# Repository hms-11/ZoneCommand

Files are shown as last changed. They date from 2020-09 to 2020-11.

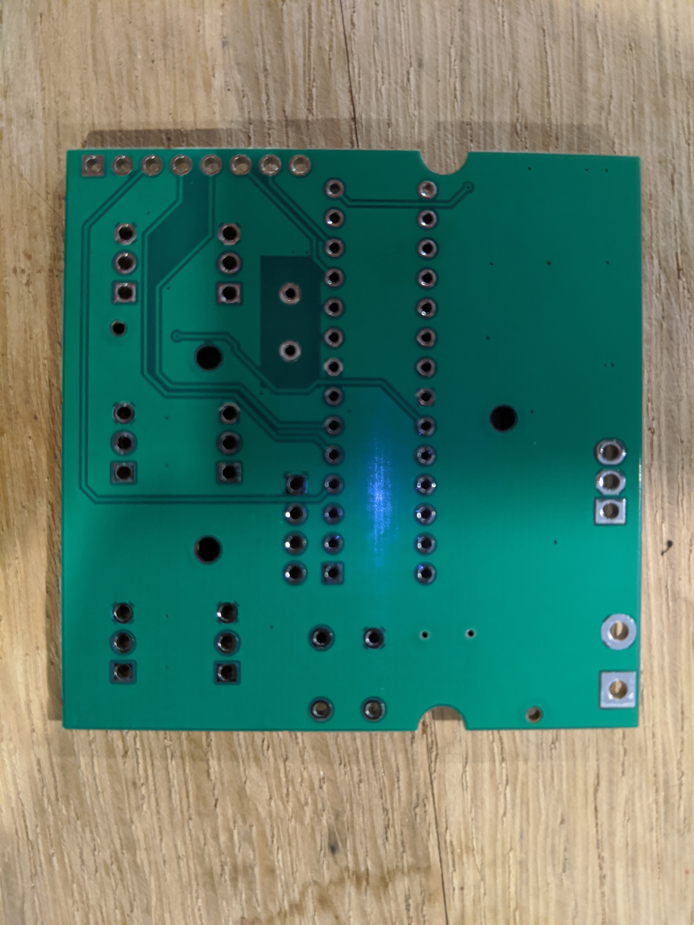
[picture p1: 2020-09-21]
IMG_20200921_071650.jpg

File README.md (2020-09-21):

# ZoneCommand
6 - Zone Control Board based on ATMEGA328P IC
Open Source 6 Zone Control Board designed to be easily configurable for a wide range of applications. 
This designed to be powered off of any 12V supply with its own on board voltage regulator (7805 footprint) to supply 5V to the board.
All inputs have an ADC as well as on-board RC filters for noise mitigation. 
Each zone has a corresponding indicator LED to let you know if the zone is active.
Outputs can be easily configured between active HIGH (5V) and active LOW (0V) in code.
Output had dedicated 5V and GND pins for outputs requiring power. 
Programming through TXD/RXD pins using a USB/Serial adapter.
All settings aim to be easily settable by the non-familiar with coding. All configuration settings aim to be well labled in the code.

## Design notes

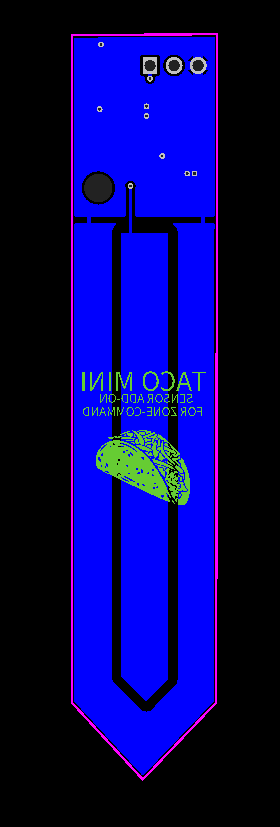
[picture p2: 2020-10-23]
PCB_PCB_2020-09-21_15-45-36_2020-10-23_11-47-11.png

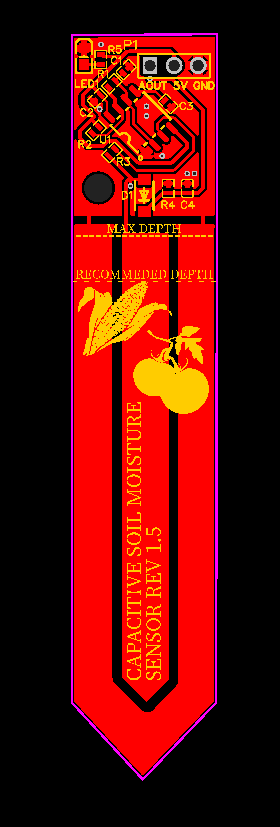
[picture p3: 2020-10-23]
PCB_PCB_2020-09-21_15-45-36_2020-10-23_11-46-59.png

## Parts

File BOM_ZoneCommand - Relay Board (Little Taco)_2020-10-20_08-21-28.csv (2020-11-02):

ID | Name | Designator | Footprint | Quantity | Manufacturer Part | Manufacturer | Supplier | Supplier Part | LCSC Assembly
1 | MMBT5551_C2145 | Q1,Q2,Q3,Q4,Q5,Q6 | SOT-23-3_L2.9-W1.3-P1.90-LS2.4-BR | 6 | MMBT5551 | CJ | LCSC | C2145 | Yes
2 | 10uF | C1 | C0805 | 1 | CL21A106KAYNNNE | SAMSUNG | LCSC | C15850 | Yes
3 | FC-2012HRK-620D | LED1,LED2,LED3,LED4,LED5,LED6 | LED0805-RD | 6 | FC-2012HRK-620D | NATIONSTAR | LCSC | C84256 | Yes
4 | 330 | R1,R2,R3,R4,R5,R6 | R0805 | 6 | 0805W8F3300T5E | UniOhm | LCSC | C17630 | Yes
5 | JQ1P-5V-F | K1,K2,K3,K4,K5,K6 | RELAY-TH_JQ1P-5V-F | 6 | JQ1P-5V-F | PANASONIC | LCSC | C58271
6 | 08JQ-BT | CN7 | CONN-TH_8P-P2.50_08JQ-BT | 1 | 08JQ-BT | JST Sales America | LCSC | C163025
7 | XY2500R-A-5.00-3P | CN1,CN2,CN3,CN4,CN5,CN6 | CONN-TH_XY2500R-A-5.00-3P | 6 | XY2500R-A-5.00-3P | -- | LCSC | C505798
8 | 510 | R7,R8,R9,R10,R11,R12 | R0805 | 6 | 0805W8F5100T5E | UniOhm | LCSC | C17734 | Yes
9 | 10K | R13,R14,R15,R16,R17,R18 | R0805 | 6 | 0805W8F1002T5E | UniOhm | LCSC | C17414 | Yes
10 | SM4007PL | D1,D2,D3,D4,D5,D6 | SOD-123F_L2.8-W1.8-LS3.7-RD | 6 | SM4007PL | MDD | LCSC | C64898 | Yes

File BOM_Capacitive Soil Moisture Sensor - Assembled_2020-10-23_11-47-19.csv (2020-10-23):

ID | Name | Designator | Footprint | Quantity | Manufacturer Part | Manufacturer | Supplier | Supplier Part | LCSC Assembly
1 | 470pF | C1 | C0402 | 1 | 0402B471K500NT | FH | LCSC | C1537 | Yes
2 | 10nF | C3 | C0402 | 1 | CL05B103KB5NNNC | SAMSUNG | LCSC | C15195 | Yes
3 | 10K | R3 | R0402 | 1 | 0402WGF1002TCE | UniOhm | LCSC | C25744 | Yes
4 | 330 | R2 | R0402 | 1 | 0402WGF3300TCE | UniOhm | LCSC | C25104 | Yes
5 | 1.6K | R1 | R0402 | 1 | 0402WGF1601TCE | UniOhm | LCSC | C4908 | Yes
6 | 1K | R5 | R0402 | 1 | 0402WGF1001TCE | UniOhm | LCSC | C11702 | Yes
7 | 1M | R4 | R0402 | 1 | 0402WGF1004TCE | UniOhm | LCSC | C26083 | Yes
8 | 1nF | C4 | C0402 | 1 | 0402B102K500NT | FH | LCSC | C1523 | Yes
9 | KT-0603R | LED1 | LED0603-R-RD | 1 | KT-0603R | KENTO | LCSC | C2286 | Yes
10 | NE555DR | U1 | SOIC-8_L4.9-W3.9-P1.27-LS6.0-BL | 1 | NE555DR | TI | LCSC | C7593 | Yes
11 | Header-Female-2.54_1x3 | P1 | HDR-TH_3P-P2.54-V | 1 | Header-Female-2.54_1x3 | Boom Precision Elec | LCSC | C146243
12 | 100nF | C2 | C0402 | 1 | CL05B104KO5NNNC | SAMSUNG | LCSC | C1525 | Yes
13 | SM4007PL | D1 | SOD-123F_L2.8-W1.8-LS3.7-RD | 1 | SM4007PL | MDD | LCSC | C64898 | Yes

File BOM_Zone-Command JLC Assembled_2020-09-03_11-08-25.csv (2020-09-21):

ID | Name | Designator | Footprint | Quantity | Manufacturer Part | Manufacturer | Supplier | Supplier Part | LCSC Assembly
1 | 22pF | C17,C9 | C0805 | 2 | CL21C220JBANNNC | SAMSUNG | LCSC | C1804 | Yes
2 | 100nF | C5,C19,C20,C21,C22,C23,C24,C11,C12,C13,C15,C16,C4,C6,C7,C3,C2,C8,C10 | C0805 | 19 | CC0805KRX7R9BB104 | YAGEO | LCSC | C49678 | Yes
3 | 10uF | C18 | C0805 | 1 | CL21A106KAYNNNE | SAMSUNG | LCSC | C15850 | Yes
4 | 1K | R4,R1,R10,R11,R12,R13,R14 | R0805 | 7 | 0805W8F1001T5E | UniOhm | LCSC | C17513 | Yes
5 | Sens6 | H7 | HDR-TH_3P-P2.54-V | 1 | Header2.54mm 1*3P | BOOMELE | LCSC | C49257
6 | Sens4 | H5 | HDR-TH_3P-P2.54-V | 1 | Header2.54mm 1*3P | BOOMELE | LCSC | C49257
7 | Sens5 | H4 | HDR-TH_3P-P2.54-V | 1 | Header2.54mm 1*3P | BOOMELE | LCSC | C49257
8 | Sens2 | H3 | HDR-TH_3P-P2.54-V | 1 | Header2.54mm 1*3P | BOOMELE | LCSC | C49257
9 | Sens1 | H2 | HDR-TH_3P-P2.54-V | 1 | Header2.54mm 1*3P | BOOMELE | LCSC | C49257
10 | Sens3 | H6 | HDR-TH_3P-P2.54-V | 1 | Header2.54mm 1*3P | BOOMELE | LCSC | C49257
11 | RB050LA-30TR | D1 | SOD-128_L3.7-W2.5-LS4.7-RD | 1 | RB050LA-30TR | ROHM Semicon | LCSC | C162057 | Yes
12 | MGGB2012M181HT-LF | L2 | L0805 | 1 | MGGB2012M181HT-LF | microgate | LCSC | C486339
13 | FC-2012HRK-620D | LED8,LED7,LED6,LED5,LED2,LED1,LED4,LED3 | LED0805-RD | 8 | FC-2012HRK-620D | NATIONSTAR | LCSC | C84256 | Yes
14 | 2PIN 12V INPUT | U4 | CONN-TH_DG500-5.08-02P-14-00A(H) | 1 | DG500-5.08-02P-14-00A(H) | DEGSON | LCSC | C691859
15 | 330 | R15,R2,R3,R5,R6,R7,R8 | R0805 | 7 | 0805W8F3300T5E | UniOhm | LCSC | C17630 | Yes
16 | Button-Reset | SW1 | SW-TH_4PIN-L6.00-W6.00 | 1 | Switch,6*6*6Plastic head,260G, 0.25mm,Straight line | BBJ | LCSC | C71836
17 | ATMEGA328P-PU | U1 | DIP-28_L34.6-W7.3-P2.54-LS10.2-BL | 1 | ATMEGA328P-PU | MICROCHIP | LCSC | C33901
18 | Programming Header 1x4 | H1 | HDR-TH_4P-P2.54-V | 1 | 210S-1*4P L=11.6MMGold-plated black | Ckmtw | LCSC | C124378
19 | L7805CV | U2 | TO-220-3_L10.0-W4.5-P2.54-L | 1 | L7805CV | STMicroelectronics | LCSC | C111887
20 | 8PIN RELAY | P1 | HDR-TH_8P-P2.54-V | 1 | Female headerHDR1X8-2.54 | BOOMELE | LCSC | C27438
21 | 10K | R16 | R0805 | 1 | 0805W8F1002T5E | UniOhm | LCSC | C17414 | Yes
22 | 1uF | C25,C1 | C0805 | 2 | CL21B105KBFNNNE | SAMSUNG | LCSC | C28323 | Yes
23 | 16MHZ | X1 | HC-49S_L11.0-W4.4-P4.88 | 1 | 5S0-1600A1620-00 | XTY | LCSC | C389708

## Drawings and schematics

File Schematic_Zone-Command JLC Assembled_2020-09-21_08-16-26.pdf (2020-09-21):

## INDICATOR LEDS

## MCU SUPPORT

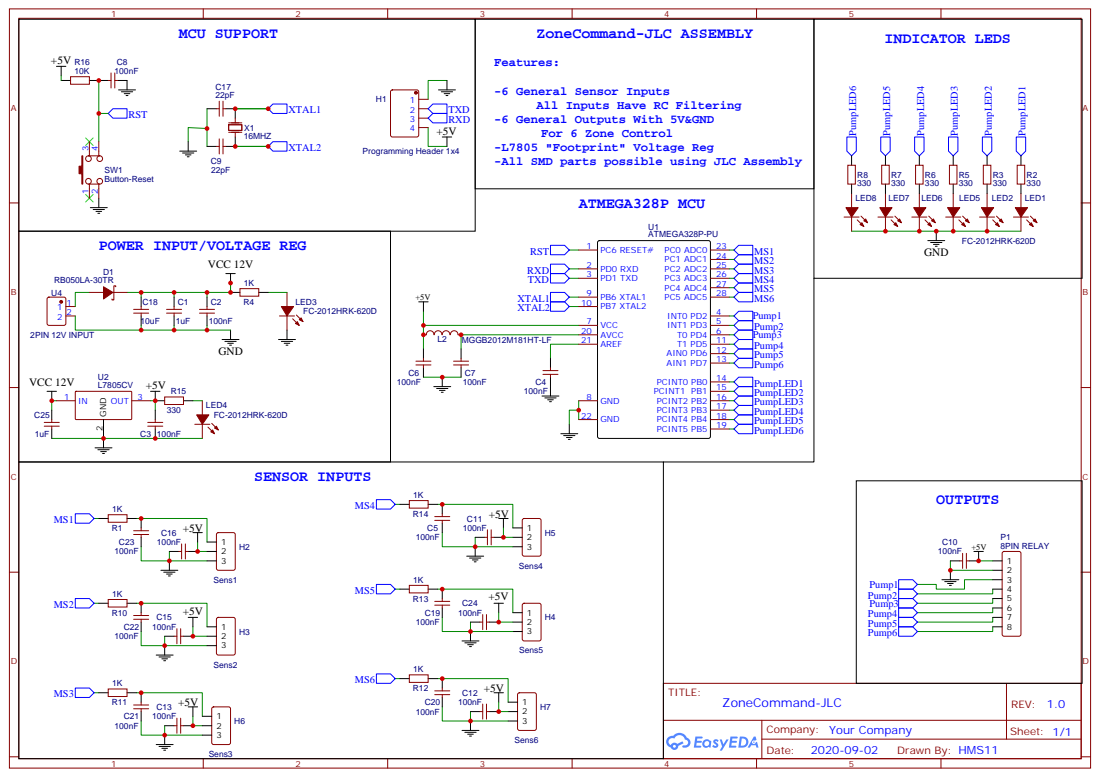
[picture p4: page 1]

All Inputs Have RC Filtering

-6 General Outputs With 5V&GND

-L7805 "Footprint" Voltage Reg
-All SMD parts possible using JLC Assembly

POWER INPUT/VOLTAGE REG

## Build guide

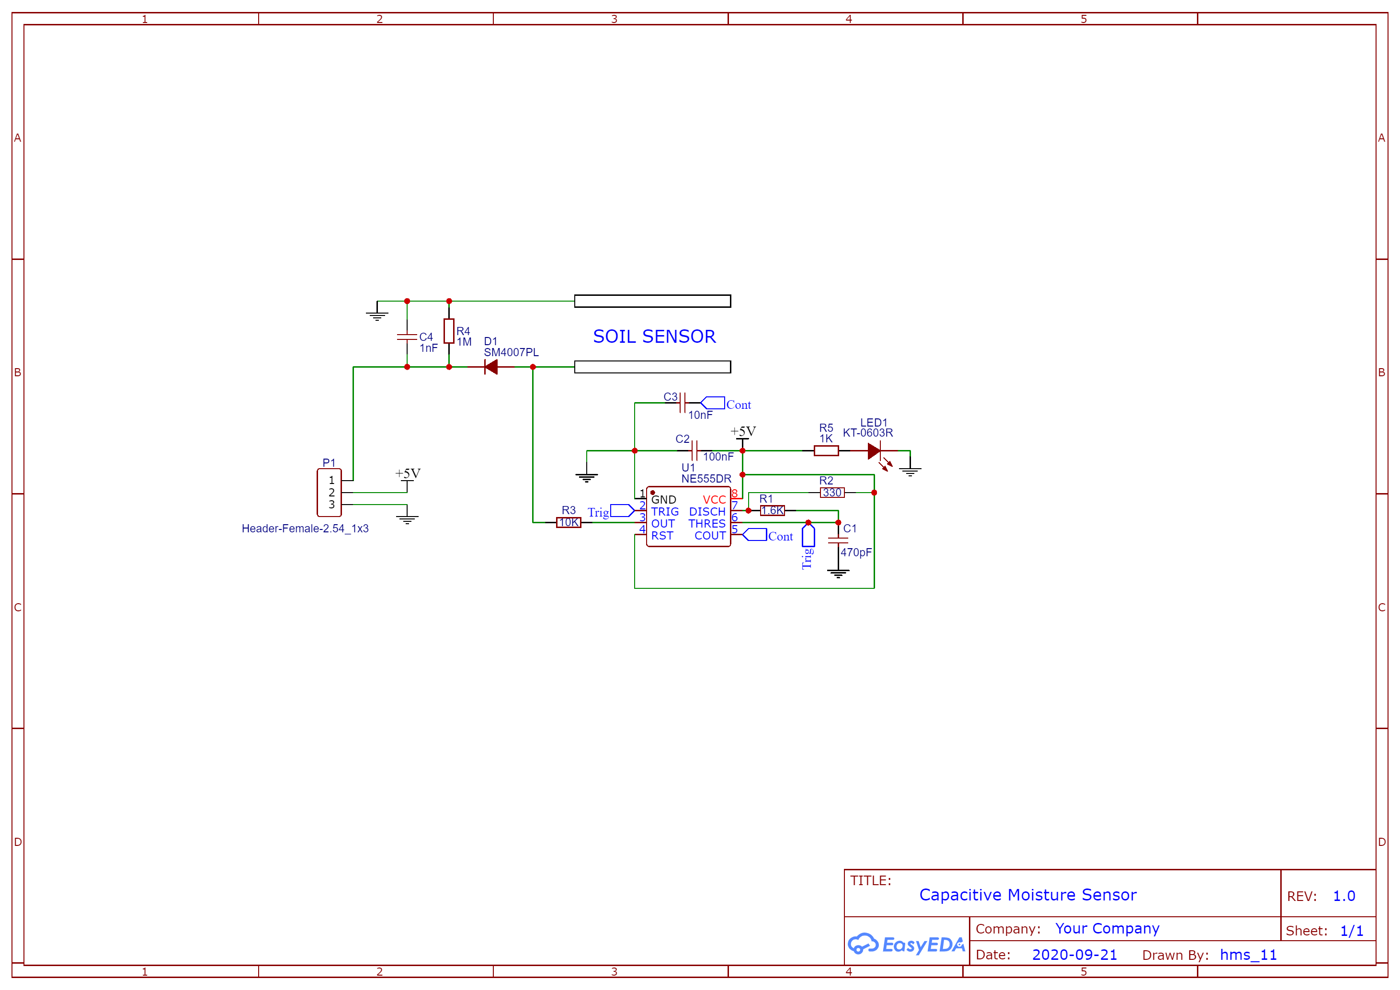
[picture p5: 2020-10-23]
Schematic_Capacitive Soil Moisture Sensor - Assembled_2020-10-23_11-46-45.png

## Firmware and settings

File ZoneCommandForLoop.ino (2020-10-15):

//  ------------------------- ZONE COMMAND ---------------------
//  ---------------------6 ZONE CONTROL BOARD-------------------

//  -------------------DESIGNED AND PROGRAMMED BY:--------------
// --------------------------COREY EARL-------------------------
// -------REVISION 3 (Simplified Code) (OCTOBER 12th, 2020)-----
// --------------All Zones Appear to Function And Debug---------
// ---------------------More Testing Needed--------------------
//----------------Ready for on-site BETA testing---------------


// print debug messages or not to serial
const bool serialDisplay = true;


///  ---------------SETTINGS-----------------

// Which zones are active. If a zone is active set as true, if a zone is deactived or not needed set to false. Zones are then placed in an array.

const bool zone1Active = true;
const bool zone2Active = true;
const bool zone3Active = true;
const bool zone4Active = true;
const bool zone5Active = true;
const bool zone6Active = true;
const bool zoneActive[6] {zone1Active, zone2Active, zone3Active, zone4Active, zone5Active, zone6Active};

// Counters for progressing through each Zone

int zoneNumber = 0; // Which zone the loop is controlling
int serialNumber = 0; // Which zone the Serial Debugger is showing

// If the relay goes active when driven low set this to true, if the relays go active when drive high set to false

const bool relayLow = true;

// If you want to trigger the outputs based on a falling value set this to true, if you want to trigger based on a raising input, set to false

const bool fallingTrigger = true;


// Sensor trigger points to trigger each zones output on. High or low "on" decided by relayLow setting

// NOTE: GIKFUN 1.2 Moisture sensors seem to range from ~340(Capacitor submerged in water) to ~670(Dry air)
//       GIKFUN 2.0 Seem to run this range (~290 wet, ~700 Dry) but responds much slower as moisture increases, responds quickly to drying).
//       These tests done with factory ~8" jumper harness. Will retest with final length harnesses and adjust



// Zone 1 setpoints
int trigger1Low = 330;
int trigger1High = 400;

// Zone 2 setpoints
int trigger2Low = 330;
int trigger2High = 400;

// Zone 3 setpoints
int trigger3Low = 330;
int trigger3High = 400;

// Zone 4 setpoints
int trigger4Low = 330;
int trigger4High = 400;

// Zone 5 setpoints
int trigger5Low = 330;
int trigger5High = 400;

// Zone 6 setpoints
int trigger6Low = 330;
int trigger6High = 400;

// Zone setpoint arrays

int triggerHigh[] {trigger1High, trigger2High, trigger3High, trigger4High, trigger5High, trigger6High}; // Puts triggerLow points in an array
int triggerLow[] {trigger1Low, trigger2Low, trigger3Low, trigger4Low, trigger5Low, trigger6Low}; // Puts triggerHigh points in an array


//// -------------------CODE----------------------

// ---Pin Assignments--

// Set Pin Assignments for Zone Status LED's

const int zone1 = 8;
const int zone2 = 9;
const int zone3 = 10;
const int zone4 = 11;
const int zone5 = 12;
const int zone6 = 13;
const int zoneLED[] {zone1, zone2, zone3, zone4, zone5, zone6}; // Puts output LEDs in an array


// Set pin assignments for OUT pins


const int out1 = 2;
const int out2 = 3;
const int out3 = 4;
const int out4 = 5;
const int out5 = 6;
const int out6 = 7;
const int output[] {out1, out2, out3, out4, out5, out6}; // Puts output pins in an array

// Set pin asignments for sensor inputs and read delays (done with millis, not delay)

const byte sens1 = A0;
const byte sens2 = A1;
const byte sens3 = A2;
const byte sens4 = A3;
const byte sens5 = A4;
const byte sens6 = A5;
const byte sens[] {sens1, sens2, sens3, sens4, sens5, sens6}; // Put analog input pins in an array

// --Variables--

// Delay Variables

const int sensorReadDelay[] {500, 500, 500, 500, 500, 500}; // delay between sensor readings in millis
unsigned long lastSensorReadTime[] {0, 0, 0, 0, 0, 0}; //the last time a sensor was read
unsigned long serialDelay = 3000; // delay between printing to serial monitor in millis
unsigned long lastSerialPrintTime = 0; // the last time the serial monitor was printed too


// Analog sensor reading values sensors 1-6
int sensor[6]; //Sensor reading values array


// Sensor pins 1-6 states ("1" = Low, "2" = Neutral, "3" = High)
int zoneState1;
int zoneState2;
int zoneState3;
int zoneState4;
int zoneState5;
int zoneState6;
int zoneState[] {zoneState1, zoneState2, zoneState3, zoneState4, zoneState5, zoneState6}; //Zone pin state array

// Output pin values outputs 1-6

int outRead1;
int outRead2;
int outRead3;
int outRead4;
int outRead5;
int outRead6;
int outRead[] {outRead1, outRead2, outRead3, outRead4, outRead5, outRead6}; // Output pin array

// Output LED pin values outputs 1-6

int outReadLED1;
int outReadLED2;
int outReadLED3;
int outReadLED4;
int outReadLED5;
int outReadLED6;
int ledState[] {outReadLED1, outReadLED2, outReadLED3, outReadLED4, outReadLED5, outReadLED6}; // Zone Active LED high/low array

// Serial States where neede
void setup() {

  // start the serial monitor and display welcome message
  Serial.begin(9600);
  delay(1000);
  Serial.println( "           Processes Started   ");
  Serial.println("           --ZONE COMMAND VERSION 1.5 (FOR LOOP CONTROL)--    ");
  Serial.println("            --6 ZONE CONTROL BOARD--     ");
  Serial.println("                       --                ");

  // set LED indicator pins to output.
  pinMode(zone1, OUTPUT);
  pinMode(zone2, OUTPUT);
  pinMode(zone3, OUTPUT);
  pinMode(zone4, OUTPUT);
  pinMode(zone5, OUTPUT);
  pinMode(zone6, OUTPUT);
  // set OUT pins to output
  pinMode(out1, OUTPUT);
  pinMode(out2, OUTPUT);
  pinMode(out3, OUTPUT);
  pinMode(out4, OUTPUT);
  pinMode(out5, OUTPUT);
  pinMode(out6, OUTPUT);
  // set sensor pins to input
  pinMode(sens1, INPUT);
  pinMode(sens2, INPUT);
  pinMode(sens3, INPUT);
  pinMode(sens4, INPUT);
  pinMode(sens5, INPUT);
  pinMode(sens6, INPUT);
}

void zoneControl() {
  if (zoneActive[zoneNumber]) {
    sensor[zoneNumber] = analogRead(sens[zoneNumber]);
    if ((unsigned long)(millis() - lastSensorReadTime[zoneNumber]) >= sensorReadDelay[zoneNumber]) {
      lastSensorReadTime[zoneNumber] = millis();

      // Set the sensor reading levels for the output trigger for sensor

      if (!fallingTrigger) { // if you want your outputs triggering on a rising value
        if (sensor[zoneNumber] <= triggerLow[zoneNumber]) {
          zoneState[zoneNumber] = 1; // Reading is below trigger, turn on relay
        }
        else if (sensor[zoneNumber] >= triggerLow[zoneNumber] && sensor[zoneNumber] <= triggerHigh[zoneNumber]) {
          zoneState[zoneNumber] = 2; // Reading is in between triggers, maintain relay state
        }
        else if (sensor[zoneNumber] >= triggerHigh[zoneNumber]) {
          zoneState[zoneNumber] = 3; // Reading is above trigger, turn off relay
        }
      }
      else if (fallingTrigger) { // if you want your outputs triggering on a falling value
        if (sensor[zoneNumber] >= triggerLow[zoneNumber]) {
          zoneState[zoneNumber] = 1; // Reading is above trigger, turn on relay
        }
        else if (sensor[zoneNumber] >= triggerLow[zoneNumber] && sensor[zoneNumber] <= triggerHigh[zoneNumber]) {
          zoneState[zoneNumber] = 2; // Reading is in between triggers, maintain relay state
        }
        else if (sensor[zoneNumber] <= triggerHigh[zoneNumber]) {
          zoneState[zoneNumber] = 3; // Reading is below trigger, turn off relay
        }
      }
    }
    
    // Trigger relays based on High/Low triggering
    if (relayLow) { //if the relays are activated by being driven low
      if (zoneState[zoneNumber] == 1) { // if the output needs to be turned on
        digitalWrite(output[zoneNumber], LOW);
        digitalWrite(zoneLED[zoneNumber], HIGH); //Turn Zone Indicator LED On
      }
      else if (zoneState[zoneNumber] == 3) { //if the output needs to be turned off
        digitalWrite(output[zoneNumber], HIGH);
        digitalWrite(zoneLED[zoneNumber], LOW); //Turn Zone Indicator LED Off
      }
    }
    else if (!relayLow) { //if the relays are actived by being driven high
      if (zoneState[zoneNumber] == 1) { // if the output needs to be turned on
        digitalWrite(output[zoneNumber], HIGH);
        digitalWrite(zoneLED[zoneNumber], HIGH); //Turn Zone Indicator LED On
      }
      else if (zoneState[zoneNumber] == 3) { //if the output needs to be turned off
        digitalWrite(output[zoneNumber], LOW);
        digitalWrite(zoneLED[zoneNumber], LOW); //Turn Zone Indicator LED Off
      }
    }
  }
}


// Display Serial debugging messages to serial monitor if serialDisplay set to true
void serialDebug() {
  // ZONE DETAILS
  if (zoneActive[serialNumber]) { // if the zone is active
    outRead[serialNumber] = digitalRead(output[serialNumber]); //check state of output
    ledState[serialNumber] = digitalRead(zoneLED[serialNumber]); //check state of zone indicator LED
    //   sensor[serialNumber] = analogRead(sens[serialNumber]); // check value of zone sensor
    Serial.println(" ZONE STATUS ");
    Serial.println("    --    ");
    Serial.println("ZONE: ");
    Serial.println(serialNumber);
    Serial.println("Output Status: (1 is 5V or HIGH, 0 is LOW or 0V)");
    Serial.print(outRead[serialNumber]);
    Serial.println("");
    Serial.println("LED Status:   ");
    Serial.print(ledState[serialNumber]);
    Serial.println("");
    Serial.println(" Sensor Value:   ");
    Serial.print(sensor[serialNumber]);
    Serial.println("");
    Serial.println("Zone State ('1' = LOW, '2' = NEUTRAL, '3' = HIGH):   ");
    Serial.print(zoneState[serialNumber]);
    Serial.println("");
    Serial.println("");
    Serial.println("");
  }

}

// Loops to progress zoneControl and serialDebug incrementally
void zoneLoop() {
  for (zoneNumber = 0; zoneNumber < 5; zoneNumber++) {
    zoneControl();
  }
  for (zoneNumber = 5; zoneNumber > 0; zoneNumber--) {
    zoneControl();
  }
}

void serialLoop() {
  if (serialDisplay) { // if debug mode is turned on
    if ((unsigned long)(millis() - lastSerialPrintTime) >= serialDelay) {
      lastSerialPrintTime = millis();
      if (relayLow) { // if the Relays are activated by a low signal
        Serial.println(" Relays are set to be activated by a LOW (0V) signal ");
      }
      else if (!relayLow) { // if the Relays are activated by a high signal
        Serial.println(" Relays are set to be activated by a HIGH (5V) signal ");
      }
      if (fallingTrigger) { // If the outputs are triggered by a falling value
        Serial.println(" Outputs are triggered on a falling value");
      }
      else if (!fallingTrigger) { // if the outputs are triggered by a rising value
        Serial.println(" Outputs are triggered on a rising value");
      }
      for (serialNumber = 0; serialNumber < 5; serialNumber++) {
        serialDebug();
      }
      for (serialNumber = 5; serialNumber > 0; serialNumber--) {
        serialDebug();
      }
    }
  }
}

void loop() {
  zoneLoop();
  serialLoop();
}

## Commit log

2020-09-21 Zone Command PCB Files
    Here are the Gerber, BOM and Pick and Place files for Zone Command - Rev2
    [BOM_Zone-Command JLC Assembled_2020-09-03_11-08-25.csv, PickAndPlace_PCB_2020-09-02_12-16-25_2020-09-03_11-08-44.csv]
2020-09-21 Zone Command PCB Files
    Schematics in PDF and Altium format
    [Sheet_1_2020-09-21_08-20-19.schdoc]
2020-09-21 PCB Rev 2 Images
    Before and after being fully assembled
2020-10-15 Create Code Rev2
    Plain code copy-paste format.
    Improvements include for-looping instead of copy-pasting zones as well as simple switching between rising/falling temperatures with a boolean statment.
    Also improved the serial debugging.
2020-10-23 Design Files For Soil Moisture Sensor
    Here is the Gerbers, Schematics and BOM for the soil moisture sensors (REV 1.5) - Improved connector location.
    [BOM_Capacitive Soil Moisture Sensor - Assembled_2020-10-23_11-47-19.csv, PickAndPlace_PCB_2020-09-21_15-45-36_2020-10-23_11-47-36.csv]
2020-11-02 DaughterBoard - 6 Transistor Driven Relays
    This add a high current/high voltage output board to ZoneCommand utilizing 6 relays driven by transistors. There are 6 indicator LED's and all relays have NC and NO applicable outlets.
    These files are panelized to allow 2 boards to be produced and assembled.
    [BOM_ZoneCommand - Relay Board (Little Taco)_2020-10-20_08-21-28.csv, PickAndPlace_PCB_2020-10-12_22-15-59_2020-10-20_08-21-46.csv]
